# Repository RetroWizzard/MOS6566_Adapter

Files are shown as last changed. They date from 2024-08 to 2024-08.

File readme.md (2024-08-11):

In this repo you will find all the files neccesary to order your pcb.
Please note that even though this design has been tested, there's still a risk of errors present in the design.

Whatever you do, <B>DO NOT UNDER ANY CIRCUMSTANCES close both jumbers at the same time!!!</B>
Doing so will send 12V into the 5V power cirquit of your computer and damage it.

By using this repository you agree that the author will not be held responsible for any damage to your hardware in any way.

Shield: [][cc-by-nc]

This work is licensed under a
[Creative Commons Attribution-NonCommercial 4.0 International License][cc-by-nc].

[][cc-by-nc]

[cc-by-nc]: https://creativecommons.org/licenses/by-nc/4.0/
[cc-by-nc-image]: https://licensebuttons.net/l/by-nc/4.0/88x31.png
[cc-by-nc-shield]: https://img.shields.io/badge/License-CC%20BY--NC%204.0-lightgrey.svg

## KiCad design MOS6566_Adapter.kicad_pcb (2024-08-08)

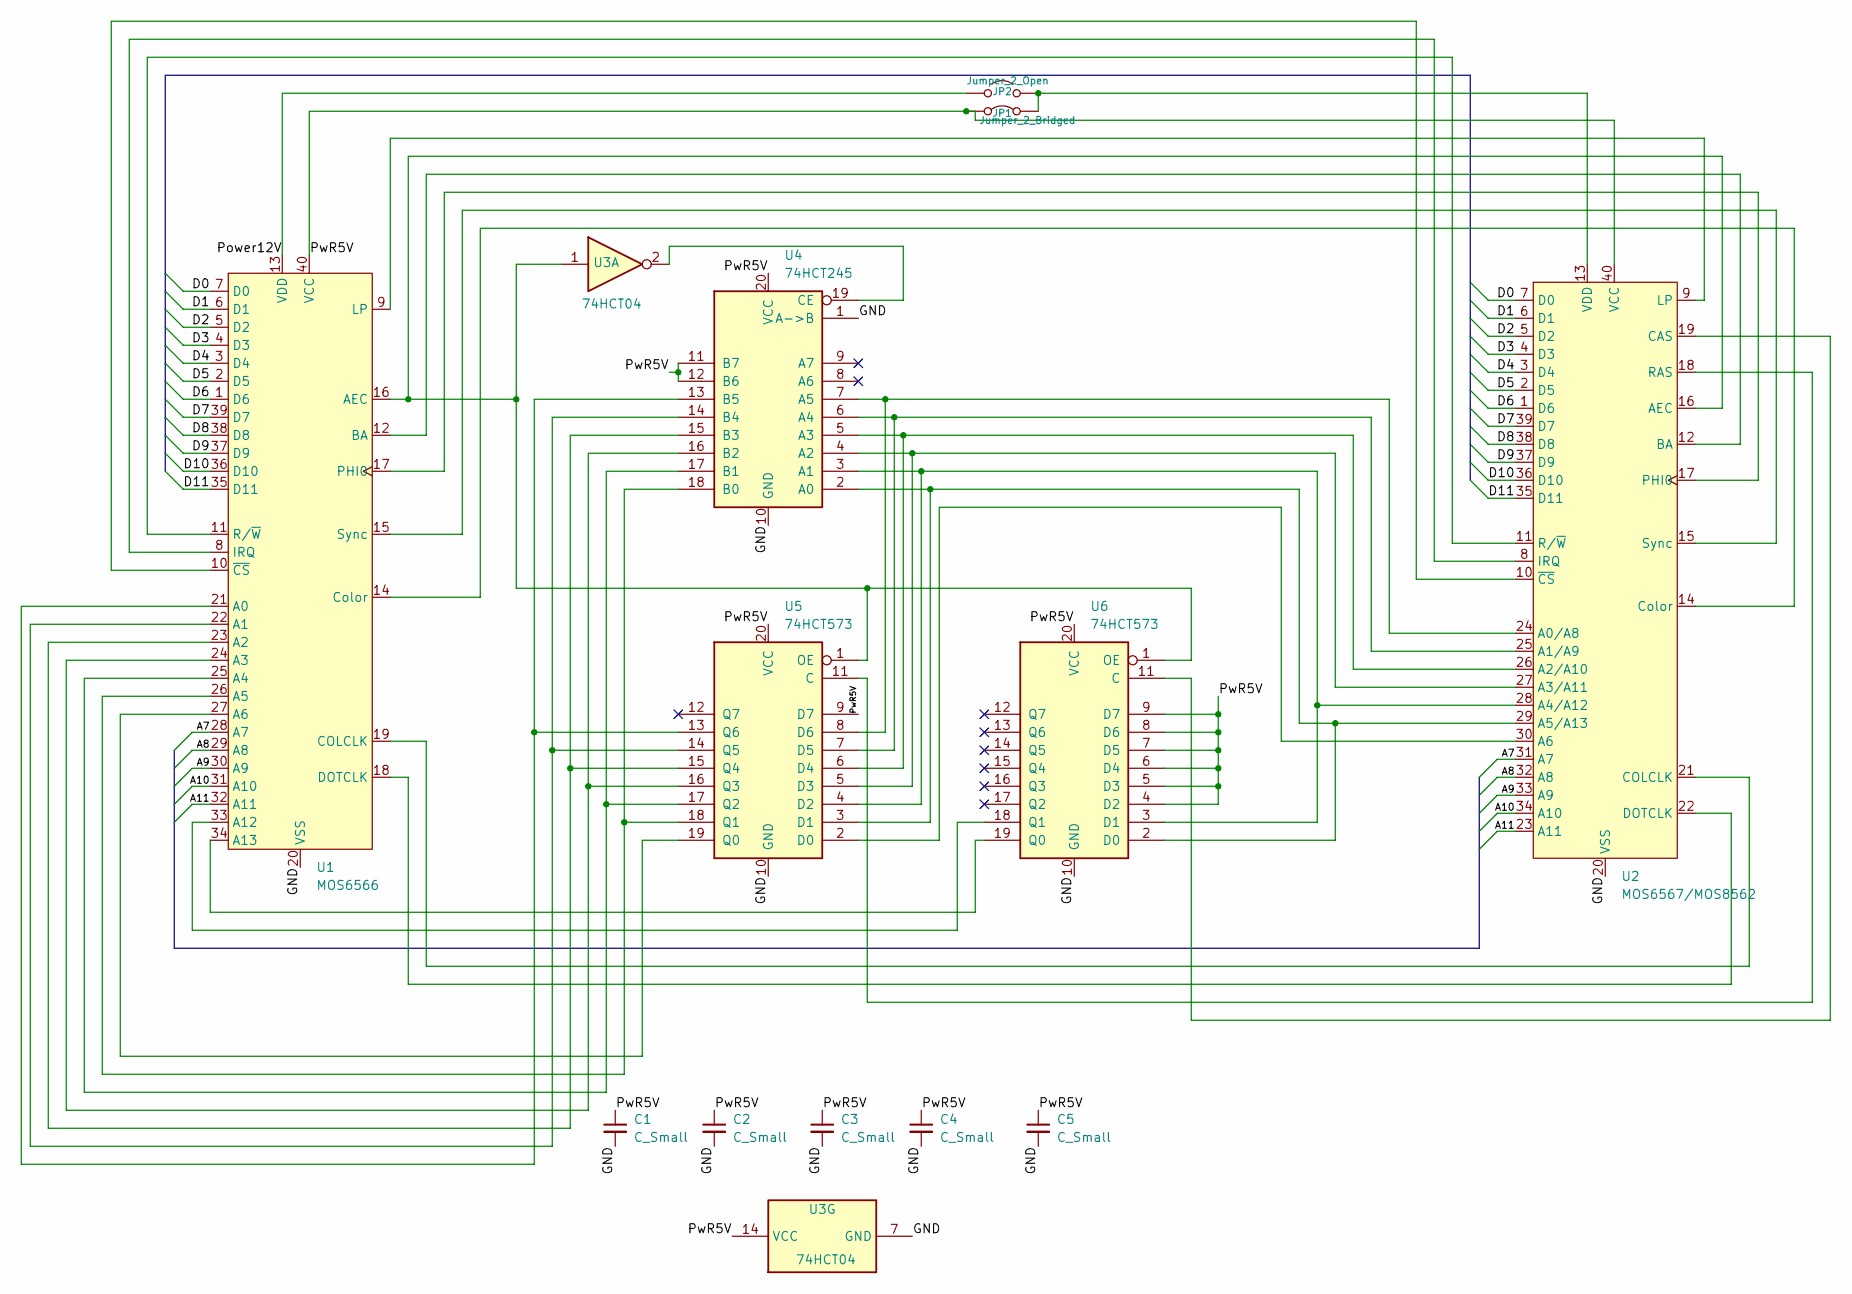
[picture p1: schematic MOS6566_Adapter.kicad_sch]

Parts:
C1, C2, C3, C4, C5: C_Small; C_Disc_D3.4mm_W2.1mm_P2.50mm
JP1: Jumper_2_Bridged; SolderJumper-2_P1.3mm_Bridged_RoundedPad1.0x1.5mm
JP2: Jumper_2_Open; SolderJumper-2_P1.3mm_Open_RoundedPad1.0x1.5mm
U1: MOS6566; DIP-40_W15.24mm_Socket
U2: MOS6567/MOS8562; DIP-40_W15.24mm_Socket
U3: 74HCT04; DIP-14_W7.62mm_Socket
U4: 74HCT245; DIP-20_W7.62mm_Socket
U5, U6: 74HCT573; DIP-20_W7.62mm_Socket

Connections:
/A7: U1.28 (A7), U2.31 (A7)
/A8: U1.29 (A8), U2.32 (A8)
/A9: U1.30 (A9), U2.33 (A9)
/A10: U1.31 (A10), U2.34 (A10)
/A11: U1.32 (A11), U2.23 (A11)
/D0: U1.7 (D0), U2.7 (D0)
/D1: U1.6 (D1), U2.6 (D1)
/D2: U1.5 (D2), U2.5 (D2)
/D3: U1.4 (D3), U2.4 (D3)
/D4: U1.3 (D4), U2.3 (D4)
/D5: U1.2 (D5), U2.2 (D5)
/D6: U1.1 (D6), U2.1 (D6)
/D7: U1.39 (D7), U2.39 (D7)
/D8: U1.38 (D8), U2.38 (D8)
/D9: U1.37 (D9), U2.37 (D9)
/D10: U1.36 (D10), U2.36 (D10)
/D11: U1.35 (D11), U2.35 (D11)
/GND: C1.2, C2.2, C3.2, C4.2, C5.2, U1.20 (VSS), U2.20 (VSS), U3.7 (GND), U4.1 (A->B), U4.10 (GND), U5.10 (GND), U6.10 (GND)
/Power12V: JP2.1 (A), U1.13 (VDD)
/PwR5V: C1.1, C2.1, C3.1, C4.1, C5.1, JP1.1 (A), U1.40 (VCC), U2.40 (VCC), U3.14 (VCC), U4.11 (B7), U4.12 (B6), U4.20 (VCC), U5.9 (D7), U5.20 (VCC), U6.4 (D2), U6.5 (D3), U6.6 (D4), U6.7 (D5), U6.8 (D6), U6.9 (D7), U6.20 (VCC)
unnamed: JP1.2 (B), JP2.2 (B), U2.13 (VDD)
unnamed: U1.21 (A0), U4.13 (B5), U5.13 (Q6)
unnamed: U1.22 (A1), U4.14 (B4), U5.14 (Q5)
unnamed: U1.23 (A2), U4.15 (B3), U5.15 (Q4)
unnamed: U1.24 (A3), U4.16 (B2), U5.16 (Q3)
unnamed: U1.25 (A4), U4.17 (B1), U5.17 (Q2)
unnamed: U1.26 (A5), U4.18 (B0), U5.18 (Q1)
unnamed: U1.27 (A6), U5.19 (Q0)
unnamed: U1.33 (A12), U6.18 (Q1)
unnamed: U1.34 (A13), U6.19 (Q0)
unnamed: U1.16 (AEC), U2.16 (AEC), U3.1, U5.1 (OE), U6.1 (OE)
unnamed: U1.12 (BA), U2.12 (BA)
unnamed: U1.19 (COLCLK), U2.21 (COLCLK)
unnamed: U1.14 (Color), U2.14 (Color)
unnamed: U1.18 (DOTCLK), U2.22 (DOTCLK)
unnamed: U1.8 (IRQ), U2.8 (IRQ)
unnamed: U1.9 (LP), U2.9 (LP)
unnamed: U1.17 (PHI0), U2.17 (PHI0)
unnamed: U1.11 (R/~W), U2.11 (R/~W)
unnamed: U1.15 (Sync), U2.15 (Sync)
unnamed: U1.10 (~CS), U2.10 (~CS)
unnamed: U2.24 (A0/A8), U4.7 (A5), U5.8 (D6)
unnamed: U2.25 (A1/A9), U4.6 (A4), U5.7 (D5)
unnamed: U2.26 (A2/A10), U4.5 (A3), U5.6 (D4)
unnamed: U2.27 (A3/A11), U4.4 (A2), U5.5 (D3)
unnamed: U2.28 (A4/A12), U4.3 (A1), U5.4 (D2), U6.3 (D1)
unnamed: U2.29 (A5/A13), U4.2 (A0), U5.3 (D1), U6.2 (D0)
unnamed: U2.30 (A6), U5.2 (D0)
unnamed: U2.19 (CAS), U6.11 (C)
unnamed: U2.18 (RAS), U5.11 (C)
unnamed: U3.2, U4.19 (CE)

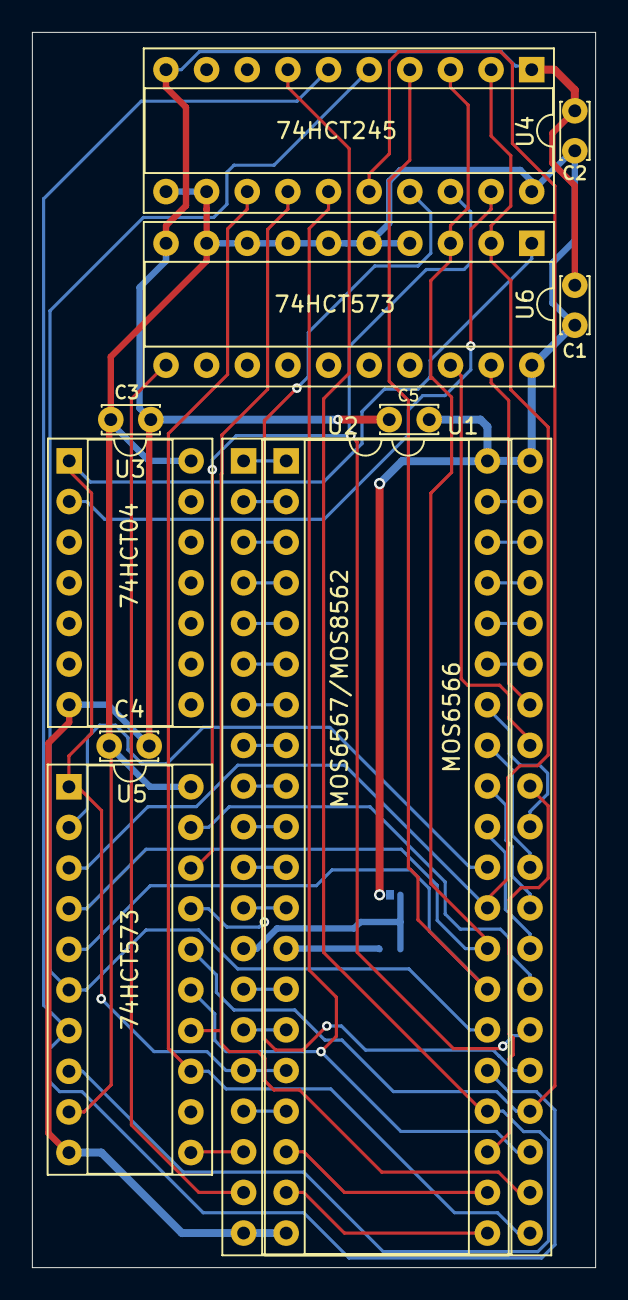
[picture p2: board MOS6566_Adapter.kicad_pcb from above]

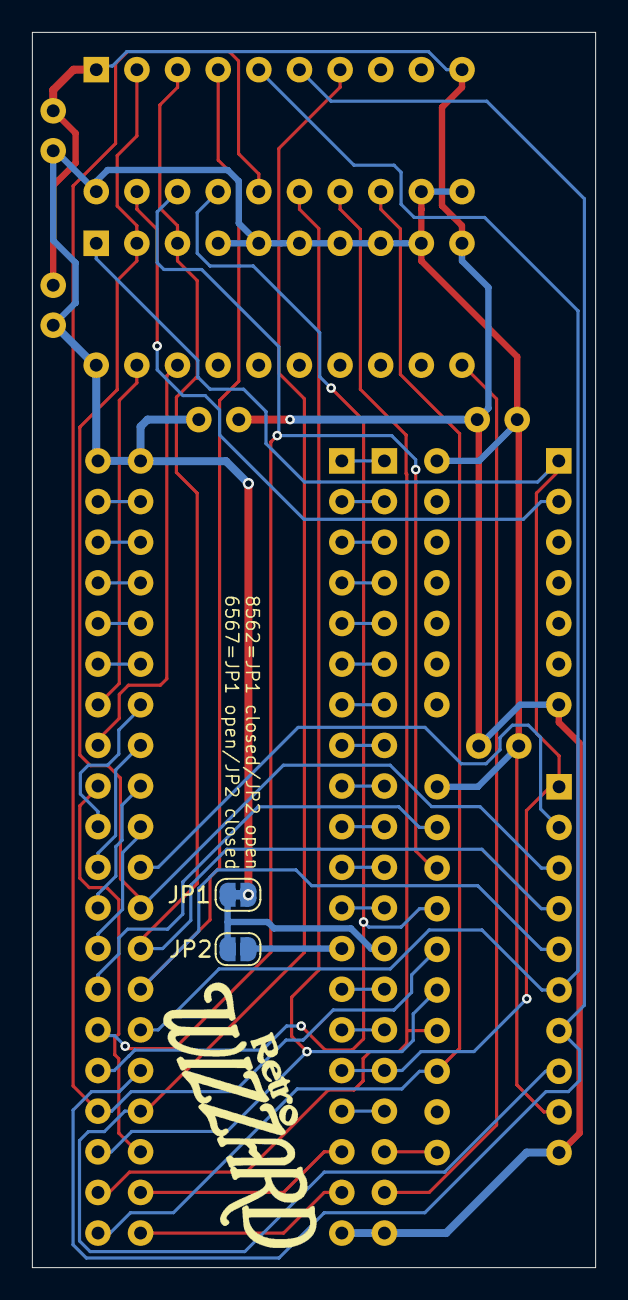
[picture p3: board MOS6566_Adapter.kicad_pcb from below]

Board: 2 copper layers, 35.2 x 77.2 mm, 13 parts (2 on the bottom side), 51 nets.

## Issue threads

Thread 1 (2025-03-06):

Possible layout issue?

TheTonyHansen, 2025-03-06:
I recently ordered this PCB from PCBWay:

https://www.pcbway.com/project/shareproject/MOS6567_MOS8562_to_MOS6566_Adapter_for_Commodore_MaxMachine_a653ed88.html

I have built this ... but each time I plug this into my Max and switch it on, it blows the fuse.

I noted that these two chips:

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

Are in reverse order to the ones shown here:

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

The rest of the PCB looks the same, so I think that's the design this one is based off?

Is that a silk-screen error?

TheTonyHansen, 2025-03-06:
Sure, here you go!

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

TheTonyHansen, 2025-03-16:
Anything look out of place?

I'm about to build another board, to see if it does the same thing. I'll socket all the chips this time around ... if it doesn't work, I'll try swapping those ICs.

TheTonyHansen, 2025-03-16:
Alas, that's two boards built, and it's the same behavior for both.  I can't upload a video apparently, so here's a link to a video of what's happening:

https://1drv.ms/v/s!AlkRWBl_PTu0t5M7EzAKeoi0jomuJQ?e=xhT4sL

RetroWizzard, 2025-03-16:
The board looks OK to me, at least from what I can see (make sure the jumper is properly cut).
When you say it blows the fuse, that indicates an issue with the 12V/5V power going the wrong way.
Are you able to test with a 8562 chip?
I will try to reproduce the error myself, but it might take me quite a while as I have a lot on my plate atm and I don't have a 6567 anymore.

TheTonyHansen, 2025-03-16:
Oddly enough, it's no longer blowing fuses.  I think maybe the bottom of the board was shorting against one of those two soldered-in caps on the board itself.  However, both boards are exhibiting the behavior shown in the video ... it looks like it's trying to do something with video, but then drops the signal.

I'm in Australia, a PAL country, so I had to import a 6567 (from Poland, from memory) in order to try this.  I don't have an 8562, and I can't see any readily available at the usual overseas suppliers at anything approaching a reasonable cost.  I don't suppose you have a spare 8562 lying around, that I could purchase?

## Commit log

2024-05-20 Version 1.0
    [MOS6566_Adapter.kicad_pcb, MOS6566_Adapter.kicad_sch]
2024-05-20 Generated Gerber files
    [MOS6566_Adapter-B_Cu.gbr, MOS6566_Adapter-B_Mask.gbr, MOS6566_Adapter-B_Paste.gbr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]
2024-06-14 New Gerbers
    [MOS6566_Adapter-B_Cu.gbr, MOS6566_Adapter-B_Mask.gbr, MOS6566_Adapter-B_Paste.gbr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]
2024-06-17 Minor cosmetics
    [MOS6566_Adapter.kicad_pcb, MOS6566_Adapter.kicad_sch]
2024-08-08 Cosmetics on silkscreen
    [MOS6566_Adapter.kicad_pcb]
2024-08-11 Updated gerbers and Readme
    [MOS6566_Adapter-B_Cu.gbr, MOS6566_Adapter-B_Mask.gbr, MOS6566_Adapter-B_Paste.gbr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]
2024-08-11 Removed old gerbers

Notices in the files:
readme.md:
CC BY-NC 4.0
